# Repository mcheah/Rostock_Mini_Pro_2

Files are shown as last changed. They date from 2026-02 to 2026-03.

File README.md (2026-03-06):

# RepRap Delta Rostock Mini Pro 2

This project has been modified with the goal of producing .step file outputs compatible with modern CAD software.  See [sources_step](sources_step/README.md) for more details.

This project offers an improved, redesigned and cleaned fork of the original sources.

### Based on the following projects:
- Rostock Mini Pro 2 (orgua) [github](https://github.com/orgua/Rostock_Mini_Pro_2)
- Rostock Mini Pro (CZAR) [thingiverse](http://www.thingiverse.com/thing:318971)
- Rostock Mini (bwevans) [thingiverse](http://www.thingiverse.com/thing:32850/) 
- Rostock (Johann) [thingiverse](http://www.thingiverse.com/thing:17175), [github](https://github.com/jcrocholl/rostock)

### Used Software: 
- [Fusion 360](https://www.autodesk.com/products/fusion-360/)
- [OpenSCAD](http://www.openscad.org) 2026.02.19 (git 10cc3aa8)
- [FreeCAD](https://www.freecad.org/) 1.1.0rc2
- [Inkscape](https://inkscape.org) 0.91

### Changes compared to Mini Pro 2 (orgua)
- Exported all scad files to .step for import into fusion 360
- Generated fusion 360 assemblies for all main components
- Added a braced version of the idler end bracket for better stiffness
- Replaced magnetic endstop with Makerbot style pcb mechanical endstop
- updated bwevan's frame generation scad to top-mounted extruders
- Added a WIP platform with 50mm radial fans

### Improvements in comparison to the Mini Pro:
- openSCAD-code base reworked
   - more modular design and more parametric
   - better documentation
   - cleaner code, no missing dependencies, less dead code
   - it's easier to make own mods
- included [bill of material](sources_bom/readme.md) and links (for orientation)
- included marlin-config (for orientation) 
- included redesign of [bottom and top plate](sources_inkscape/readme.md) (Inkscape svg)
- more space under the printer (there is just USB and power coming out of mine)
   - this design allows shorter wires to the motors and results in better EMC
   - shock absorbing standoffs (if printed with soft PLA)
   - better cooling for motors
   - allows active cooling for motor-drivers
- better stability, less wiggle, stiffer frame, better print-quality
   - better fin-design for all plate-connecting parts
   - design of hotend-mount is much more sturdy 
   - allow two lm8uu per rod (4 per carriage)
- the fan of the E3D-Hotend fits between hotend-mount and platform
   - hotend is lifted and print-space in z-direction is bigger 
- included space / cutout for nuts on more places
- hal-sensor-end-stops with better repeatability 
- better cable-management
- includes a filament-holder on top of the printer
- direct mounting at carriage of open belt-ends with zip-ties (with belt_mount_for_carriage.scad) 
   - groves secure belt-mount 
- built in power-switch next to the heat-bed

### Still to do: 
- include cooling into platform
- add more pictures
- further optimize the code 
- document hal-sensor-board
- motor-mount: add even more space above the motor for better cooling

### Pictures (in progress):

Front

TOP

DETAIL

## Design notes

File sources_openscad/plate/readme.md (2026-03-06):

# Frame 2d files
These files are taken from the original [Rostick Mini release on thingiverse, by bwevans](https://www.thingiverse.com/thing:32850).  They have been simplified and modified to make compatible with the other Rostock Mini Pro updates.  The original .dxf files had segmented polygons instead of circular holes, which make it difficult to import into Fusion 360.

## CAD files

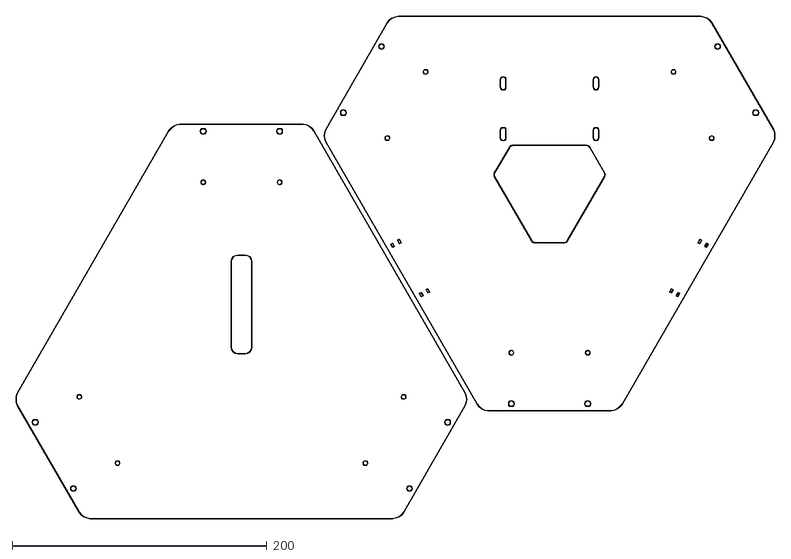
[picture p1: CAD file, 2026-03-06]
sources_openscad/plate/both_frames.dxf
596.4 x 394.7

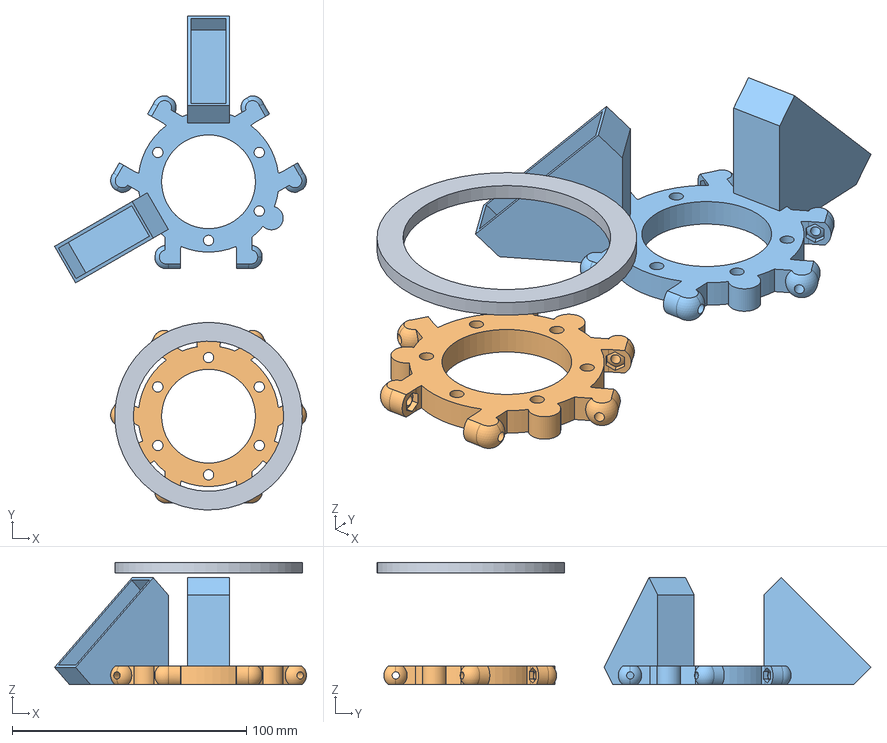
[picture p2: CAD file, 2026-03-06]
sources_step/platform.step
107.5 x 210.7 x 52.3 mm

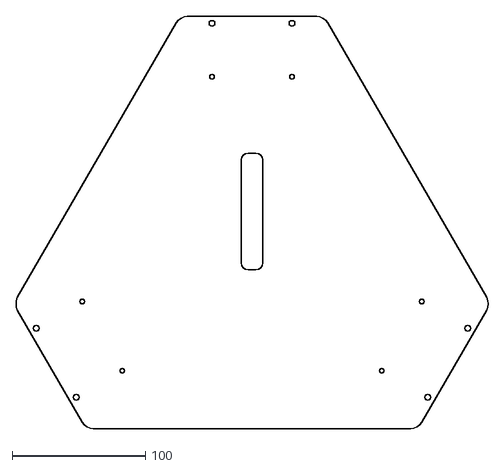
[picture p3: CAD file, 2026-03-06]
sources_openscad/plate/lower_frame.dxf
354.2 x 309.9

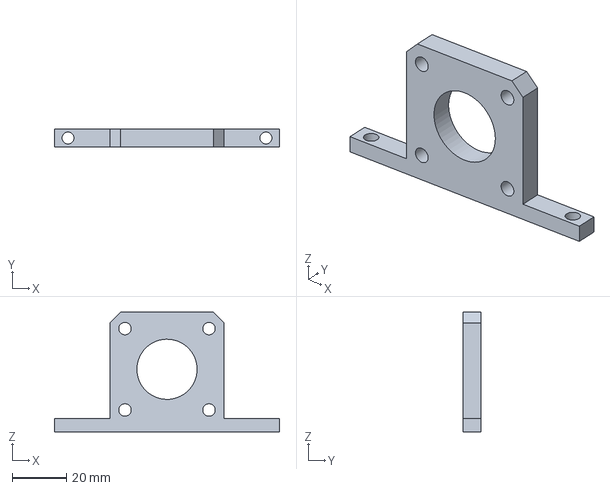
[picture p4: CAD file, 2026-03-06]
sources_step/extruder_bracket_spacer.step
83.0 x 6.80 x 44.2 mm

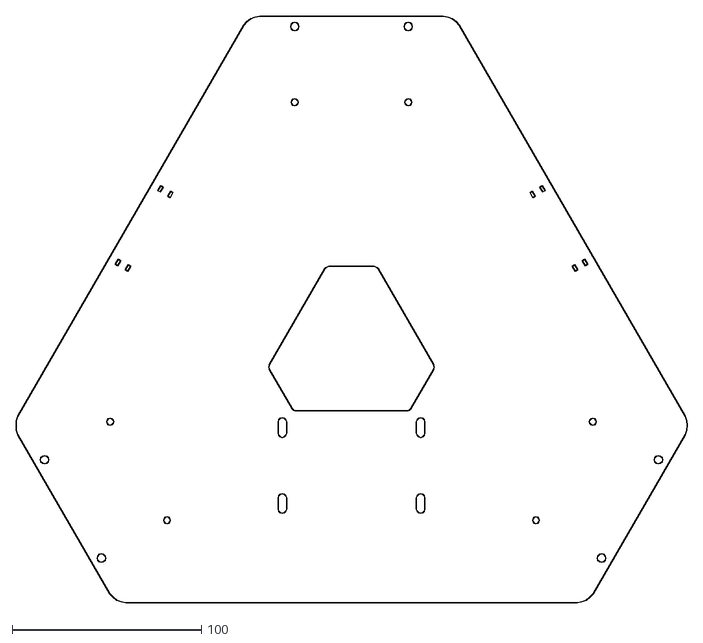
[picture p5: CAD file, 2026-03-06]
sources_openscad/plate/upper_frame.dxf
354.2 x 309.9

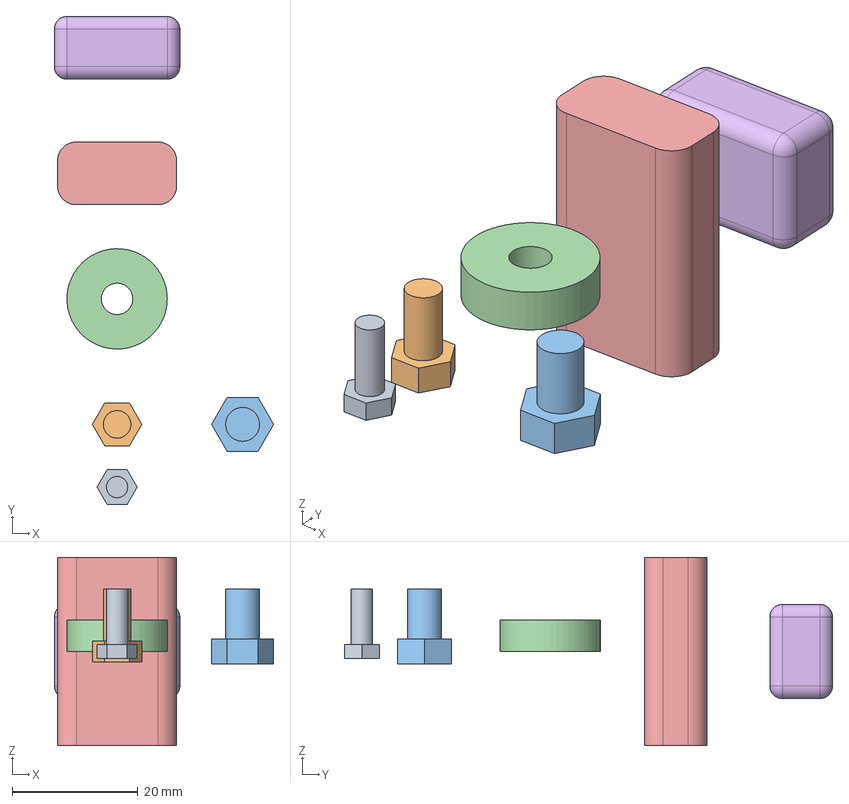
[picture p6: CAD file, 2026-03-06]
sources_step/misc_parts.step
35.0 x 77.8 x 30.0 mm

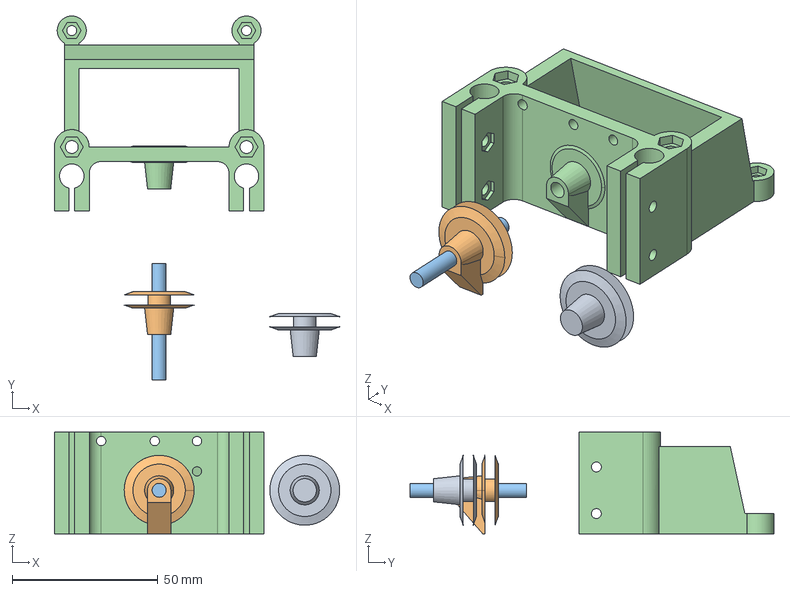
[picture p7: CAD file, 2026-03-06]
sources_step/idler_end2.step
98.0 x 125.0 x 35.0 mm
Matrix_Union

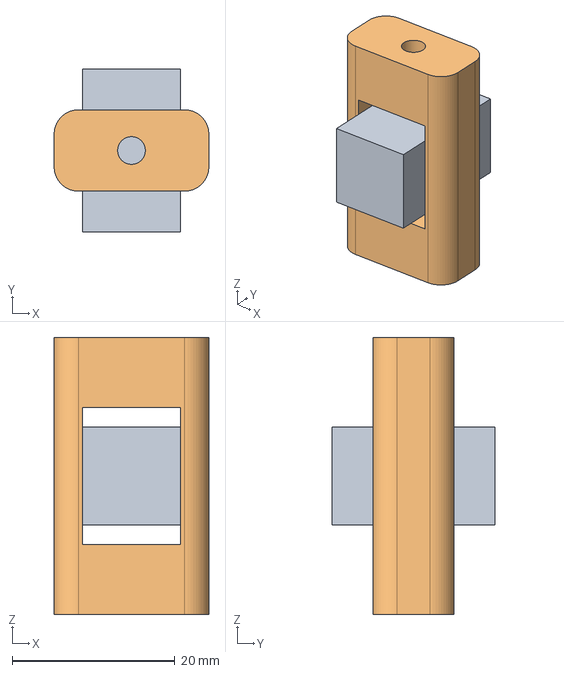
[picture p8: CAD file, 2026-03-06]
sources_step/hotend_mount_spacer_square.step
19.0 x 20.0 x 34.0 mm

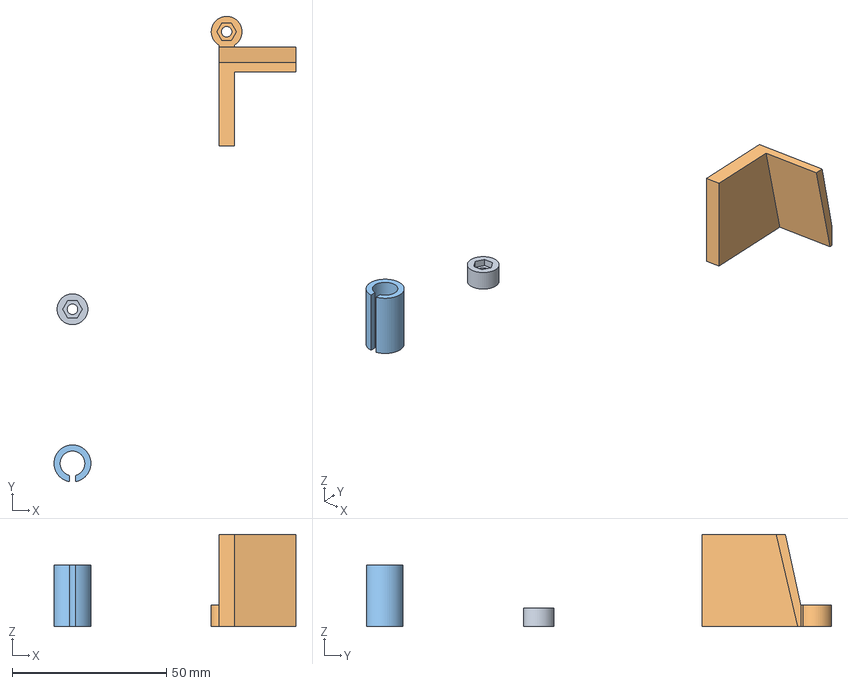
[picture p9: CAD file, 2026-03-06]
sources_step/bracket.step
78.5 x 150.9 x 30.0 mm

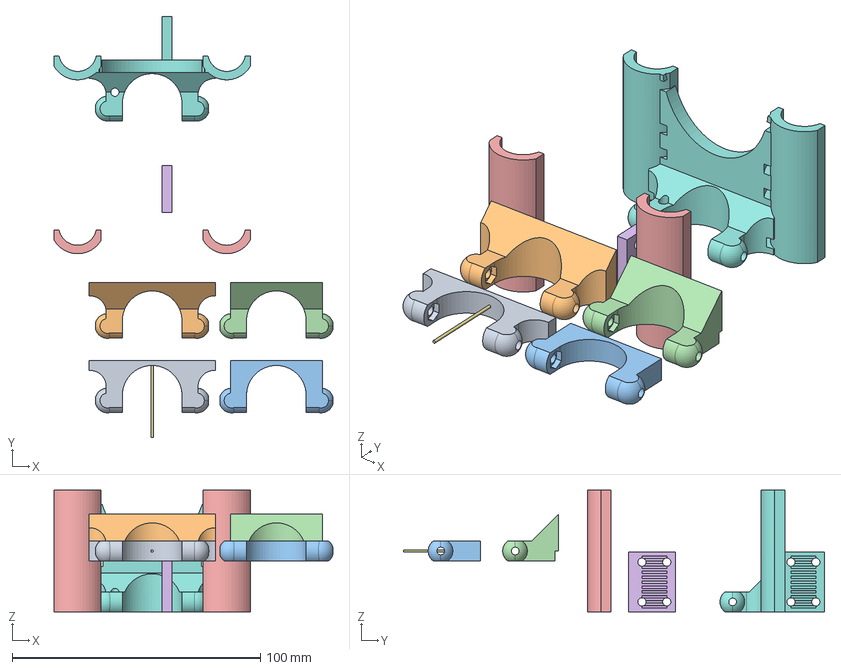
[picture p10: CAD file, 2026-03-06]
sources_step/carriage_for_traxxas.step
112.3 x 169.5 x 49.0 mm

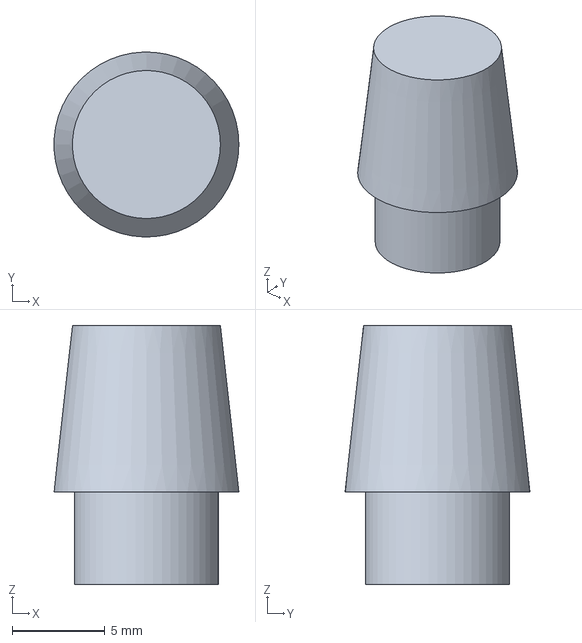
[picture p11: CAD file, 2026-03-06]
sources_step/pulley_spacer.step
9.99 x 10.00 x 14.0 mm

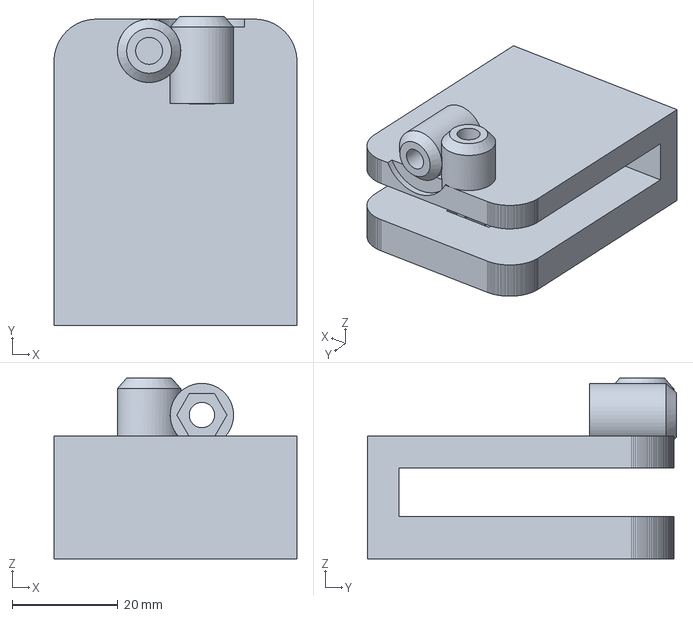
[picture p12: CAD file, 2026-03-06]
sources_step/filament_holder_clamp.step
46.0 x 58.5 x 34.3 mm

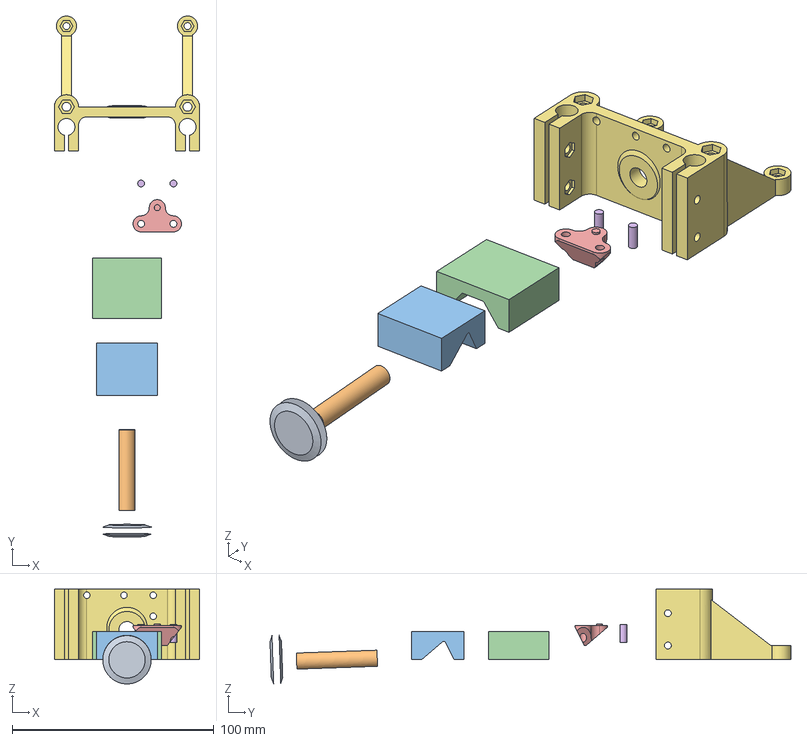
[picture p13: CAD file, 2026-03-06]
sources_step/idler_end.step
72.0 x 258.2 x 47.0 mm
polyhedron
polyhedron001

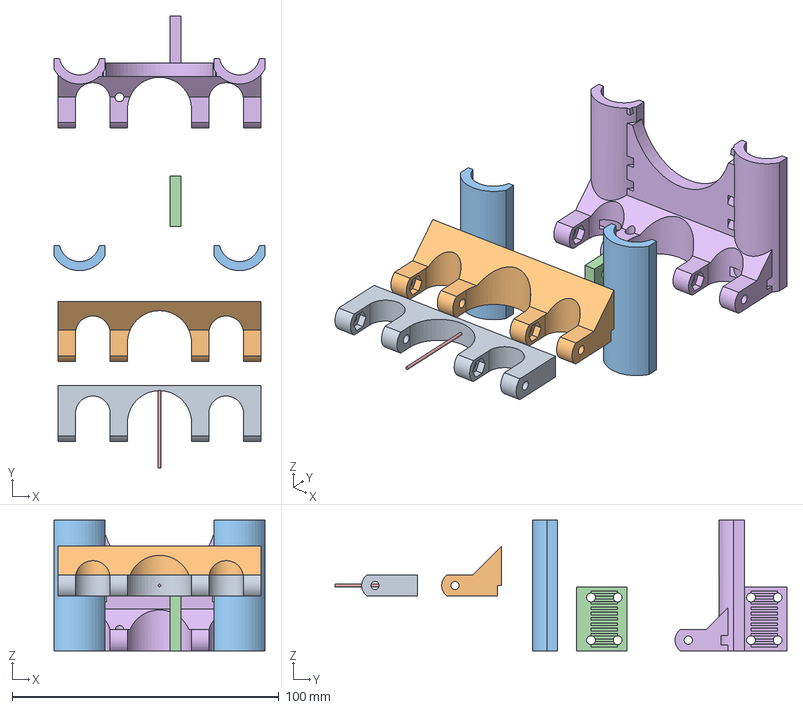
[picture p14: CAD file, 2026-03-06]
sources_step/carriage_for_jaws.step
79.0 x 169.5 x 49.0 mm

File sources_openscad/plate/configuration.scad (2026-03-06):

motor_end_height=44;
idler_end_height=28;
carriage_height=24;
platform_thickness=8;

sanguinololu=true;					// places mounting holes for the Sanguinololu controller
carbon_rods=true;					// turns on option for carbon diagonal rods just for looks!

frame_thickness=6;   				// 6mm acrylic
pcb_thickness=2;						// used for rendering PCB and approximating build volume

smooth_rod_length=750;  				// determins vertical build height with 508 for 8" 
rod_diameter=8;						// might be interesting to have larger rods
platform_hinge_offset=33;
carriage_hinge_offset=22;

printbed=[155,155];  				// printrbed 6x6 -  210,210 for prusa 8x8 platform
printbed_screw_spacing=[146.5,147]; 	// sets screw spacing for heated bed default: printrbed

//tower_radius = printbed[0]*0.9;
tower_radius = 176.65125712828054705002952581722;
rod_length=printbed[0]*1.2;

corner_radius=12;
//frame_radius=(tower_radius-rod_diameter/2-corner_radius)/cos(30);
//frame_radius=((500-24)*sqrt(3))/3.3
frame_radius=262.43194054073898386779490022816;

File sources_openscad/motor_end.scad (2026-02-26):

/*
Info:
This design fits a nema17. You should print this with support, so that you get a clean motor-hole. Otherwise you could comment-out code below - look for "printable_without_support". You need 3 of these parts.

Improvement:
- better fin-design
- included space / cutout for nuts 

TODO: 
- resize part, for some air above and below the motor

*/

motor_front_dimension         = 42;
motor_front_hole_radius       = 11.3;
motor_mounting_screw_distance = 31;

printable_without_support     = false;

part_extraheight_top    =  1; // between motor and bottom-plate
part_extraheight_bottom = 12; // between motor and base

$fn=36;

include <bracket_inc.scad>
use <bracket.scad>
include <misc_parts_inc.scad>
use <misc_parts.scad>

// negative parts that get substracted
module motor_holes() 
{
    sh = 10;
    sd = motor_mounting_screw_distance/2;
    sr = M3_screw_hole_dia/2; 
    fr = motor_front_hole_radius;
    
    cylinder(r=fr, h=sh, center=true); 
    // make it printable without support!
    if (printable_without_support) 
    {
        translate([0,8,+(fr+1)/2]) rotate([0,0,45]) cube(fr, center=true);
        translate([0,8,-(fr+1)/2]) rotate([0,0,45]) cube(fr, center=true);
    }
    translate([+sd,+sd,0]) cylinder(r=sr, h=sh, center=true);
    translate([+sd,-sd,0]) cylinder(r=sr, h=sh, center=true);
    translate([-sd,+sd,0]) cylinder(r=sr, h=sh, center=true);
    translate([-sd,-sd,0]) cylinder(r=sr, h=sh, center=true);
}

translate([0,80,motor_front_dimension/2+part_extraheight_top]) rotate([90,0,0]) motor_holes();


module motor_end() 
{
    hf  = motor_front_dimension;
    heb = part_extraheight_bottom;
    het = part_extraheight_top;
    hm  = motor_front_dimension + heb + het;
    wr  = rod_distance;

    difference() 
    {
        union() 
        {
            translate([0,0,hm/2]) bracket(hm);
            translate([+wr/2,10,0]) diagonal_fin2(35, 7, 40, 30, 5);
            translate([-wr/2,10,0]) diagonal_fin2(35, 7, 40, 30, 5);
        }
        translate([0,8,hf/2+het]) rotate([90,0,0]) motor_holes();
        for (z=[8:13:(hm-7)]) for (i=[-1,1])
            translate([i*(wr/2-6),-6, z]) rotate([0,i*90,0]) rotate([0,0,30]) screw_M3(25);
    }
}

motor_end();

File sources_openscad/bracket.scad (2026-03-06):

/* 
Info: 
This part is just a template for the other parts of the linear drive.

Improvement: 
- diagonal fin is parametrised and reusable
- remove screw-models --> put in misc-parts

TODO: 
- 
*/

$fn = 36;
$fa = 12;
$fs = 0.5;

include <bracket_inc.scad>
include <misc_parts_inc.scad>
use <misc_parts.scad>


//// fin-module
// height1: front of fin
// height2: back of fin
// length1: length all together
// length2: length of the fin-part that gets merged in the adjacent part
// width:   ....
use <prism.scad>
module diagonal_fin2(height1, height2, length1, length2, width) 
{
    ds = 3; // =y0, distance from the endpoints
    y1 = (length1-length2)/2;
    y2 = (length1+length2)/2;
    y3 = length1 - ds;
    surface = [ [0,ds], [height1,ds], [height1,y1], [height2,y2], [height2,y3], [0,y3] ];
    union() 
    {
        rotate([0,-90,0]) prism(surface,width,center=true);
        // mounting screw hole.
        translate([0, length1, height2/2]) difference() 
        {
            cylinder(r=5, h=height2, center=true);
            translate([0,0,height2/2-1]) rotate([0,180,0]) screw_M3(10); 
        }
   }
}

translate([0,100,0]) diagonal_fin2(40, 6, 50, 40, 5);

module diagonal_fin3(height1, height2, length1, length2,length3, width,width2) 
{
    ds = 3; // =y0, distance from the endpoints
    y1 = (length1-length2)/2;
    y2 = (length1+length2)/2;
    y3 = length1 - ds;
    surface = [ [0,ds], [height1,ds], [height1,y1], [height1,30],
    [height2,y2], [height2,y3], [0,y3] ];
    wall_surface = [ [0,y3-length3], [height1,30-length3], [
    height1,30], [height2,y2], [0,y2] ];
    union() 
    {
        rotate([0,-90,0]) linear_extrude(width,center=true) polygon(points=surface);  
        translate([width2/2+width/2,0,0]) rotate([0,-90,0]) linear_extrude(width2,center=true) polygon(points=wall_surface);
        // mounting screw hole.
        translate([0, length1, height2/2]) difference() 
        {
            cylinder(r=5, h=height2, center=true);
            translate([0,0,height2/2-1]) rotate([0,180,0]) screw_M3(10); 
        }
   }
   echo(y1);
   echo(y2);
   echo(y3);
}

translate([50,100,0]) diagonal_fin3(30,7,40,30,3.0,5,20);

module bracket(height) 
{
    w = rod_distance;
    difference() 
    {
        union() 
        {
            translate([0, -1, 0]) cube([w+12, 22, height], center=true);
            // Sandwich mount hull
            translate([-w/2, 10, 0]) cylinder(r=6, h=height, center=true);
            translate([+w/2, 10, 0]) cylinder(r=6, h=height, center=true);
        }
        // Sandwich mount screw holes
        translate([-w/2, 10, height/2-1]) rotate([0,180,0]) screw_M4(height);
        translate([+w/2, 10, height/2-1]) rotate([0,180,0]) screw_M4(height);

        // Smooth rod mounting slots.
        for (x = [-w/2, w/2])
        {
            translate([x, 0, 0]) 
            {
                cylinder(r=rod_hole_radius, h=height+1, center=true);
                translate([0, -10, 0]) cube([2, 20, height+1], center=true);
            }
        }
        // Belt path.
        translate([0, -5, 0]) cube([w-20, 20, height+1], center=true);
        translate([0, -9, 0]) cube([w-12, 20, height+1], center=true);
        translate([-w/2+10, 1, 0]) cylinder(r=4, h=height+1, center=true);
        translate([+w/2-10, 1, 0]) cylinder(r=4, h=height+1, center=true);
    }
}

translate([0, 0, 10]) bracket(20);

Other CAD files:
sources_step/plate_spacer.step
sources_step/filament_holder_topmount.step
sources_step/frame.step
sources_step/endstop_template.step
sources_openscad/bracket_inc.scad
sources_f3d/17HS19-2004S1.f3d
sources_f3d/belt_mount_for_carriage.f3d
sources_f3d/bracket.f3d
sources_f3d/bracket_V2.f3d
sources_f3d/carriage_for_jaws.f3d
sources_f3d/carriage_for_traxxas.f3d
sources_f3d/debug_drive_with_carriage.f3d
sources_f3d/debug_drive_with_carriage_V2.f3z
sources_f3d/debug_drive_with_carriage_f3d.f3z
sources_f3d/debug_platform_with_hotend_mount.f3d
sources_f3d/debug_platform_with_hotend_mount_f3d.f3z
sources_f3d/debug_rostock.f3d
sources_f3d/debug_rostock_with_plates_V2.f3z
sources_f3d/debug_rostock_with_plates_f3d.f3z
sources_f3d/endstop_template.f3d
sources_f3d/extruder_bracket_spacer.f3d
sources_f3d/fan_mount.f3d
sources_f3d/filament_holder.f3d
sources_f3d/filament_holder_clamp.f3z
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

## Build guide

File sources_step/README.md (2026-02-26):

.step files are generated by importing each .scad manually into FreeCAD and exporting to .step.  Use `export_scad.py \<stepFileName\>` to automate this process.  Note that the appropriate paths need to be setup to refer to theFreeCAD python environment.  use export_scad_macos.zsh` to see how this is
managed.

Some notes on OpenSCAD compatibility with FreeCAD:
- FreeCAD does not parse 2d shapes correctly when importing.  This means that linear_extrude operations should be replaced with the 3d equivalent operations when possible
    - cylinder instead of circle
    - cube instead of square
    - prism instead of polygon
- DXF files need to be directly imported to FreeCAD manually and extruded
- FreeCAD seems to have trouble with complex unions and difference operations.  When possible it may be necessary to re-partition operations or re-order equivalent fuse operations to avoid crashes when exporting
- the `export_scad.py` script currently attempts to only export the top level geometries, which results in components being fused as a single part.  To preserve these individual components the `\<PreserveNodes\>` parameter can be used to keep shapes by name.  This is a largely manual process.

step files exported using OpenSCAD version 2026.02.19 (git 10cc3aa8) and FreeCAD version 1.1.0rc2 with the OpenSCAD workbench enabled

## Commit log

2026-02-24 updated to clear warnings with openscad 2026
    [platform.scad]
2026-02-26 Modified files to import to FreeCAD cleanly. Added step versions of models and added export_scad scripts
    [belt_mount_for_carriage.step, bracket.scad, bracket.step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]
2026-03-05 Added fusion 360 imports of step files and assemblies
    [belt_mount_for_carriage.f3d, bracket.f3d, carriage_for_traxxas.f3d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]
2026-03-06 Added frame scad files from https://www.thingiverse.com/thing:32850/files
    [both_frames.dxf, bracket.scad, configuration.scad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]
2026-03-06 Added several changes to brackets and frame files
    [17HS19-2004S1.f3d, bracket.scad, bracket.step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]
